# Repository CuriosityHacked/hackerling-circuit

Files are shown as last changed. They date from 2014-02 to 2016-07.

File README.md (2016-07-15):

hackerling-circuit
==================

The eagle design files and supporting documents for the Hackerling Circuit

Be sure to look at the wiki https://github.com/CuriosityHacked/hackerling-circuit/wiki to see the intstructions and more info.

Curiosity Hacked sells full hackerling circuit kits! info@curiosityhacked.org for info. $45 for all the parts and the board prepopulated with SMD accelerometer components.

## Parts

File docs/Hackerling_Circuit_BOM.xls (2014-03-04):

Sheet: v1.3
Part number | qnty
k1 | 1 | 40 pin straight header | S1012EC-40-ND | CONN HEADER .100" SNGL STR 40POS | digikey
k2 | 2 | 330 Ohm resistor array | CSC330N-ND | RES ARRAY 330 OHM 7 RES 8-SIP | digikey
k3 | 1 | Green 5MM LED | 100QBK-ND | RES 100 OHM 1/4W 5% CARBON FILM | digikey
k4 | 1 | Speaker | 254-EMB15-RO | MINI TONE TRANSDUCER | Mouser
k5 | 1 | 100 Ohm Resistor | 100QBK-ND | RES 100 OHM 1/4W 5% CARBON FILM | digikey
k6 | 1 | B-12 Switch | 633-B12JH |  | Mouser
k7 | 1 | 8 pin io expander | MCP23008-E/P-ND | IC I/O EXPANDER I2C 8B 18DIP | digikey
k8 | 1 | 16 pin io expander | MCP23017-E/SP-ND | IC I/O EXPANDER I2C 16B 28SDIP | digikey
k9 | 1 | Bargraph LED Array | 604-DC10GWA |  | Mouser
k10 | 2 | 100 Ohm resistor array | 4608X-2-101LF-ND | RES ARRAY 100 OHM 4 RES 8SIP | digikey
k11 | 1 | Dip Switch | CT2094MS-ND | SWITCH RAISED ACTUATOR 4 SEC | digikey
k12 | 4 | 4x Buttons | SW413-ND | SWITCH TACTILE SPST-NO 0.05A 24V | digikey
k13 | 1 | Red cap | SW260-ND | KEYCAP 12MM SQ RED FITS 12MM | digikey
k14 | 1 | Orange cap | SW956-ND | KEYCAP 12MM SQ ORANGE FITS | digikey
k15 | 1 | Green Cap | SW957-ND | KEYCAP 12MM GRN FITS 12MM | digikey
k16 | 1 | Blue Cap | SW258-ND | KEYCAP 12MM SQ BLUE FITS 12MM | digikey
k17 | 1 | 47 Ohm resistor | 47QBK-ND | RES 47 OHM 1/4W 5% CARBON FILM | digikey
k18 | 1 | 10 uF cap | 445-2863-ND | CAP CER 10UF 6.3V 10% RADIAL | digikey
k19 | 1 | IR photo detector | 425-2501-ND | RECEIVER IR REM CTRL 5V 38KHZ | digikey
k20 | 2 | IR LED | 475-1200-ND | EMITTER IR 850NM 5MM RADIAL | digikey
k21 | 1 | 6 pin right angle header | S1112EC-40-ND | CONN HEADER .100" SNGL R/A 40POS | digikey
k22 | 1 | 502kOhm resistor | 412KXBK-ND | RES 412K OHM 1/4W 1% METAL FILM | digikey
k23 | 1 | 100 Kohm thermistor | BC2424-ND | THERMISTOR NTC 330K 5% RADIAL | digikey
k24 | 1 | 10k pot | PTV09A-4225F-B103-ND | POT 10K OHM 9MM SQ .05W CARB | digikey
k25 | 1 | Pot cap | 450-2034-GRX | KNOB FOR 1/4" SHAFT | Mouser
k26 | 1 | 100 Ohm Pot | 3306K-103-ND | TRIMMER 10K OHM 0.2W PC PIN | digikey
k27 | 1 | 16x2 char LCD | 668-NC-S16205DFYSAY |  | Mouser
a1 | 1 | Accelerometer | 841-MMA8452QR1 | IC ACCELEROMETER 3AXIS 16QFN | Mouser
a2 | 2 | 470 ohm resistor | RMCF0603JT470RCT-ND | RES 470 OHM 1/10W 5% 0603 | digikey
a3 | 1 | 200K resistor | 311-200KGRCT-ND | RES 200K OHM 1/10W 5% 0603 SMD | digikey
a4 | 1 | I2c Level shifter | 296-17988-1-ND | IC VOLT LEVEL TRANSLATOR 8-VSSOP | digikey
a5 | 1 | 4.7 uF Cap | 399-3482-1-ND | CAP CER 4.7UF 6.3V 10% X5R 0603 | digikey
a6 | 2 | 4k7 resistor | CR0603-JW-472ELFCT-ND | RES 4.7K OHM 1/10W 5% 0603 SMD | digikey
a7 | 1 | .1 uF Cap | 311-1341-1-ND | CAP CER 0.1UF 25V 10% X7R 0603 | digikey
a8 | 1 | 1 uF cap | 311-1372-1-ND | CAP CER 1UF 16V Y5V 0603 | digikey
a9 | 1 | 3.3V power supply | TC1016-3.3VCTCT-ND | IC REG LDO 3.3V 80MA SOT23-5 | digikey

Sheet: v1.2
Index | Quantity | Part Number | Description |  | Customer Reference | Quantity needed | Unit Price USD
1 | 30 | CT2094MS-ND | SWITCH RAISED ACTUATOR 4 SEC |  | SW1 | 1 | 0.683 | 0.683
2 | 30 | 445-2863-ND | CAP CER 10UF 6.3V 10% RADIAL | FOR IR RECIEVER | C4 | 1 | 0.328 | 0.328
3 | 25 | 425-2501-ND | RECEIVER IR REM CTRL 5V 38KHZ | FOR IR RECIEVER | IR1 | 1 | 0.768 | 0.768
4 | 30 | 3306K-103-ND | TRIMMER 10K OHM 0.2W PC PIN |  | U8 | 1 | 0.3456 | 0.3456
5 | 30 | 311-1355-1-ND | CAP CER 10UF 10V Y5V 0805 | Optional (to be removed) | C5 | 1 | 0.0824 | 0.0824
6 | 100 | 47QBK-ND | RES 47 OHM 1/4W 5% CARBON FILM | FOR IR RECIEVER | R6 | 1 | 0.0242 | 0.0242
7 | 100 | 311-47ARCT-ND | RES 47 OHM 1/8W 5% 0805 SMD | Optional (to be removed) | R7 | 1 | 0.0077 | 0.0077
8 | 120 | SW413-ND | SWITCH TACTILE SPST-NO 0.05A 24V |  | B1,B2,B3,B4 | 4 | 0.4253 | 1.7012
9 | 100 | 311-1372-1-ND | CAP CER 1UF 16V Y5V 0603 |  | C1 | 1 | 0.0186 | 0.0186
10 | 50 | 399-3482-1-ND | CAP CER 4.7UF 6.3V 10% X5R 0603 |  | C3 | 1 | 0.0518 | 0.0518
11 | 25 | MCP23008-E/P-ND | IC I/O EXPANDER I2C 8B 18DIP |  | IC2 | 1 | 0.85 | 0.85
12 | 100 | 475-1200-ND | EMITTER IR 850NM 5MM RADIAL |  | LED1,LED2,LED3 | 3 | 0.3879 | 1.1637
13 | 60 | CSC330N-ND | RES ARRAY 330 OHM 7 RES 8-SIP |  | RN3,RN4 | 2 | 0.231 | 0.462
14 | 30 | MMA8452QT-ND | IC ACCELEROMETER 3AXIS 16QFN |  | U1 | 1.5 | 1.168 | 1.752
15 | 100 | 296-17988-1-ND | IC VOLT LEVEL TRANSLATOR 8-VSSOP |  | U5 | 1 | 0.3159 | 0.3159
16 | 20 | S1012EC-40-ND | CONN HEADER .100" SNGL STR 40POS |  | STRAIGHT HEADERS | 2 | 0.459 | 0.918
17 | 5 | S1112EC-40-ND | CONN HEADER .100" SNGL R/A 40POS |  | RIGHT ANGLE HEADER | 0.1 | 0.64 | 0.064
18 | 30 | BC2424-ND | THERMISTOR NTC 330K 5% RADIAL |  | R1 | 1 | 0.264 | 0.264
19 | 100 | 412KXBK-ND | RES 412K OHM 1/4W 1% METAL FILM |  | R2 | 1 | 0.0315 | 0.0315
20 | 1 | EG2448-ND | SWITCH TOGGLE SPDT .4VA RT ANG |  | SW2 ALT | 1 | 3.22 | 3.22
21 | 30 | TC1016-3.3VCTCT-ND | IC REG LDO 3.3V 80MA SOT23-5 |  | IC3 | 1 | 0.3 | 0.3
 |  |  |  |  |  |  |  | 0
20 |  | LCD-226 | LCD screen |  |  | 1 | 6.00 | 6 | allelectronics
20 |  | BG-10G | bargraph |  |  | 1 | 1.25 | 1.25 | allelectronics
20 |  | KNB-124 | knob for pot |  |  | 1 | 0.65 | 0.65 | allelectronics
20 |  | PE-52 | buzzer |  |  | 1 | 0.50 | 0.5 | allelectronics
 |  |  | Board |  |  | 1 | 10 | 10
 |  | 652-PTV09A-4225FB102 |  |  |  | 1 | 0.62 | 0.62
 |  | 633-B12JH |  |  |  | 1 | 3.46 | 3.46
 |  | 579-MCP23017-E/SP |  |  |  | 1 | 1 | 1
 |  |  | arduino uno |  |  |  |  | 26.95
 |  |  |  |  |  |  |  | 63.7816

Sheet: v1.1
board part ID | My part ID | description | value | size | qnty used | price |  | Use notes | Retail ID | Retailor | Manufacturer's id
 | MTS-86RT | DPDT ON-ON MINI-TOGGLE SWITCH |  |  |  | 1.25 |  | maybe too big? | MTS-86RT | AllElectronics
R1 | TNR-103 | 10K OHM NTC THERMISTOR |  |  | 1 | 0.65 |  |  | TNR-103 | AllElectronics
 | PE-52 | MINI TONE TRANSDUCER |  |  |  | 0.5 |  |  | PE-52 | AllElectronics
SG1 | PE-38 | MINI TONE TRANSDUCER |  | 0.82" DIA. X 0.15" | 1 | 0.334 |  |  | PE-38 | AllElectronics
 | PB-214 | JUMBO PUSHBUTTON, GREEN |  |  | 0 | 3.75 |  |  | PB-214 | AllElectronics
U2 | LCD-226 | 16 X 2 LCD W/ LED BACKLIGHT |  |  |  | 6 |  |  | LCD-226 | AllElectronics
 | LCD-2161 | 16 X 1 LCD W/ LED BACKLIGHT |  |  |  | 3 |  |  | LCD-2161 | AllElectronics
 | LCD-8002 | 8 CHARACTER X 2 LINE LCD |  |  |  | 3.25 |  |  | LCD-8002 | AllElectronics
 | BG-10G | 10 SEGMENT BARGRAPH, GREEN |  |  |  | 1.5 |  |  | BG-10G | AllElectronics
 | KNB-124 | KNOB FOR 1/4" SHAFT |  |  |  | 0.75 |  |  | KNB-124 | AllElectronics
 | LPC-10K | 10K LIN. POT W/CTR DETENT, PC MT |  |  |  | 0.25 |  |  | LPC-10K | AllElectronics
 | DWS-4S | 4-POLE DIP SWITCH, LOW PROFILE |  |  |  | 1 | digikey | CT2094MS-ND | DWS-4S | AllElectronics
 | CSC330N-ND | RES ARRAY 330 OHM 7 RES 8-SIP |  |  | 2 | 0.49 |  |  | CSC330N-ND | Digikey |  | RN1, RN2 | $1.96
 | 296-17988-1-ND | IC VOLT LEVEL TRANSLATOR 8-VSSOP |  |  | 1 | 0.96 |  |  | 296-17988-1-ND | Digikey |  | I2C TRANSLATOR | $3.84
 | MMA8452QT-ND | IC ACCELEROMETER 3AXIS 16QFN |  |  | 1 | 1.31 |  |  | MMA8452QT-ND | Digikey |  | ACCELEROMETER | $5.24
 | TC1016-3.0VCTCT-ND | IC REG LDO 3V 80MA SOT23-5 |  |  | 0 | 0.43 |  |  | TC1016-3.0VCTCT-ND | Digikey |  | 3.3V REG | $1.72
 | 1219-1083-1-ND | IC REG LDO 3V SOT23-5 |  |  | 1 | 0.4 |  |  | 1219-1083-1-ND | Digikey |  | 3V REG | $1.60
 | MCP23008-E/P-ND | IC I/O EXPANDER I2C 8B 18DIP |  |  | 1 | 1.22 |  |  | MCP23008-E/P-ND | Digikey |  |  | $4.88
 | 1050-1024-ND | ARDUINO UNO BOARD REV3 |  |  | 1 | 26.39 |  |  | 1050-1024-ND | Digikey |  |  | $52.78
 | MCP23017-E/SP-ND | IC I/O EXPANDER I2C 16B 28SDIP |  |  | 1 | 1.44 |  |  | MCP23017-E/SP-ND | Digikey |  |  | $5.76
 | SW414-ND | SWITCH TACTILE SPST-NO 0.05A 24V |  |  | 4 | 0.5124 |  |  | SW414-ND | Digikey |  |  | $12.81
 | SW957-ND | KEYCAP 12MM GRN FITS 12MM |  |  | 1 | 0.279 |  |  | SW957-ND | Digikey |  |  | $2.79
 | SW956-ND | KEYCAP 12MM SQ ORANGE FITS |  |  | 1 | 0.279 |  |  | SW956-ND | Digikey |  |  | $2.79
 | SW260-ND | KEYCAP 12MM SQ RED FITS 12MM |  |  | 1 | 0.279 |  |  | SW260-ND | Digikey |  |  | $2.79
 | SW258-ND | KEYCAP 12MM SQ BLUE FITS 12MM |  |  | 1 | 0.279 |  |  | SW258-ND | Digikey |  |  | $2.79
 | 475-1200-ND | EMITTER IR 850NM 5MM RADIAL |  |  |  | 0.428 |  |  | 475-1200-ND | Digikey |  |  | $4.28
 | EG4912-ND | SWITCH TOGGLE SPDT .4VA R/A |  |  | 1 | 2.99 |  |  | EG4912-ND | Digikey |  |  | $5.98
 | B13EH-ND | SW TOGGLE SPDT .4VA RA BRKT ESD |  |  | 0 | 4.2 |  |  | B13EH-ND | Digikey |  |  | $8.40
 | 425-2501-ND | RECEIVER IR REM CTRL 5V 38KHZ |  |  | 1 | 0.96 |  |  | 425-2501-ND | Digikey |  |  | $3.84
 | 311-1372-1-ND | CAP CER 1UF 16V Y5V 0603 |  |  |  | 0.041 |  |  | 311-1372-1-ND | Digikey |  |  | $0.41
 | 399-3482-1-ND | CAP CER 4.7UF 6.3V 10% X5R 0603 |  |  |  | 0.09 |  |  | 399-3482-1-ND | Digikey |  |  | $0.90
 | 311-200KGRCT-ND | RES 200K OHM 1/10W 5% 0603 SMD |  |  | 1 | 0.0048 |  |  | 311-200KGRCT-ND | Digikey |  |  | $0.48
R3,R4 | CR0603-JW-472ELFCT-ND | RES 4.7K OHM 1/10W 5% 0603 SMD |  |  |  | 0.0044 |  |  | CR0603-JW-472ELFCT-ND | Digikey |  |  | $0.44
 | 311-1341-1-ND | CAP CER 0.1UF 25V 10% X7R 0603 |  |  |  | 0.01 |  |  | 311-1341-1-ND | Digikey |  |  | $1.00
 |  |  |  |  |  | 65.2306

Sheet: Sheet2
therm | 1 | 2 | 3 | 4 | 5 | 6 | 7 | 8 | 9 | 10 | 11 | 12 | 13 | 14 | 15 | 16 | 17 | 18 | 19 | 20 | 21 | 22
1 | 0.500 | 0.667 | 0.750 | 0.800 | 0.833 | 0.857 | 0.875 | 0.889 | 0.900 | 0.909 | 0.917 | 0.923 | 0.929 | 0.933 | 0.938 | 0.941 | 0.944 | 0.947 | 0.950 | 0.952 | 0.955 | 0.957
2 | 0.333 | 0.500 | 0.600 | 0.667 | 0.714 | 0.750 | 0.778 | 0.800 | 0.818 | 0.833 | 0.846 | 0.857 | 0.867 | 0.875 | 0.882 | 0.889 | 0.895 | 0.900 | 0.905 | 0.909 | 0.913 | 0.917
3 | 0.250 | 0.400 | 0.500 | 0.571 | 0.625 | 0.667 | 0.700 | 0.727 | 0.750 | 0.769 | 0.786 | 0.800 | 0.812 | 0.824 | 0.833 | 0.842 | 0.850 | 0.857 | 0.864 | 0.870 | 0.875 | 0.880
4 | 0.200 | 0.333 | 0.429 | 0.500 | 0.556 | 0.600 | 0.636 | 0.667 | 0.692 | 0.714 | 0.733 | 0.750 | 0.765 | 0.778 | 0.789 | 0.800 | 0.810 | 0.818 | 0.826 | 0.833 | 0.840 | 0.846
5 | 0.167 | 0.286 | 0.375 | 0.444 | 0.500 | 0.545 | 0.583 | 0.615 | 0.643 | 0.667 | 0.688 | 0.706 | 0.722 | 0.737 | 0.750 | 0.762 | 0.773 | 0.783 | 0.792 | 0.800 | 0.808 | 0.815
6 | 0.143 | 0.250 | 0.333 | 0.400 | 0.455 | 0.500 | 0.538 | 0.571 | 0.600 | 0.625 | 0.647 | 0.667 | 0.684 | 0.700 | 0.714 | 0.727 | 0.739 | 0.750 | 0.760 | 0.769 | 0.778 | 0.786
7 | 0.125 | 0.222 | 0.300 | 0.364 | 0.417 | 0.462 | 0.500 | 0.533 | 0.562 | 0.588 | 0.611 | 0.632 | 0.650 | 0.667 | 0.682 | 0.696 | 0.708 | 0.720 | 0.731 | 0.741 | 0.750 | 0.759
8 | 0.111 | 0.200 | 0.273 | 0.333 | 0.385 | 0.429 | 0.467 | 0.500 | 0.529 | 0.556 | 0.579 | 0.600 | 0.619 | 0.636 | 0.652 | 0.667 | 0.680 | 0.692 | 0.704 | 0.714 | 0.724 | 0.733
9 | 0.100 | 0.182 | 0.250 | 0.308 | 0.357 | 0.400 | 0.438 | 0.471 | 0.500 | 0.526 | 0.550 | 0.571 | 0.591 | 0.609 | 0.625 | 0.640 | 0.654 | 0.667 | 0.679 | 0.690 | 0.700 | 0.710
10 | 0.091 | 0.167 | 0.231 | 0.286 | 0.333 | 0.375 | 0.412 | 0.444 | 0.474 | 0.500 | 0.524 | 0.545 | 0.565 | 0.583 | 0.600 | 0.615 | 0.630 | 0.643 | 0.655 | 0.667 | 0.677 | 0.688
 | 0.2424242424 | 0.3333333333 | 0.3692307692 | 0.380952381 | 0.380952381 | 0.375 | 0.3660130719 | 0.3555555556 | 0.3444976077 | 0.3333333333 | 0.3223443223 | 0.3116883117 | 0.3014492754 | 0.2916666667 | 0.2823529412 | 0.2735042735 | 0.2651072125 | 0.2571428571 | 0.249589491 | 0.2424242424 | 0.2356241234 | 0.2291666667
 | 0.05194805195 | 0.08333333333 | 0.1025641026 | 0.1142857143 | 0.1212121212 | 0.125 | 0.1266968326 | 0.126984127 | 0.1263157895 | 0.125 | 0.1232492997 | 0.1212121212 | 0.118993135 | 0.1166666667 | 0.1142857143 | 0.1118881119 | 0.1095008052 | 0.1071428571 | 0.1048275862 | 0.1025641026 | 0.1003584229 | 0.09821428571

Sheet: Sheet3
board part ID | My part ID | description | value | size | qnty used | qnty have | price | Use notes | Retail ID | Retailor | Manufacturer's id
 | MTS-86RT | DPDT ON-ON MINI-TOGGLE SWITCH |  |  |  | 2 | 1.25 | maybe too big? | MTS-86RT | AllElectronics
R1 | TNR-103 | 10K OHM NTC THERMISTOR |  |  | 1 | 3 | 0.65 |  | TNR-103 | AllElectronics
SG1 | PE-38 | MINI TONE TRANSDUCER |  | 0.82" DIA. X 0.15" | 1 | 3 | 0.334 |  | PE-38 | AllElectronics
 | PB-214 | JUMBO PUSHBUTTON, GREEN |  |  | 0 | 1 | 3.75 |  | PB-214 | AllElectronics
 | LCD-2161 | 16 X 1 LCD W/ LED BACKLIGHT |  |  |  | 2 | 3 |  | LCD-2161 | AllElectronics
 | LCD-8002 | 8 CHARACTER X 2 LINE LCD |  |  |  | 2 | 3.25 |  | LCD-8002 | AllElectronics
 |  |  |  |  |  |  |  |  |  |  |  | I2C TRANSLATOR | $3.84
 | TC1016-3.0VCTCT-ND | IC REG LDO 3V 80MA SOT23-5 |  |  | 0 | 4 | 0.43 |  | TC1016-3.0VCTCT-ND | Digikey |  | 3.3V REG | $1.72
 | 1219-1083-1-ND | IC REG LDO 3V SOT23-5 |  |  | 1 | 4 | 0.4 |  | 1219-1083-1-ND | Digikey |  | 3V REG | $1.60
 | EG4912-ND | SWITCH TOGGLE SPDT .4VA R/A |  |  | 1 | 2 | 2.99 |  | EG4912-ND | Digikey |  |  | $5.98
 | B13EH-ND | SW TOGGLE SPDT .4VA RA BRKT ESD |  |  | 0 | 2 | 4.2 |  | B13EH-ND | Digikey |  |  | $8.40
 | SW957-ND | KEYCAP 12MM GRN FITS 12MM |  |  | 1 | 10 | 0.279 |  | SW957-ND | Digikey |  |  | $2.79
 | SW956-ND | KEYCAP 12MM SQ ORANGE FITS |  |  | 1 | 10 | 0.279 |  | SW956-ND | Digikey |  |  | $2.79
 | SW260-ND | KEYCAP 12MM SQ RED FITS 12MM |  |  | 1 | 10 | 0.279 |  | SW260-ND | Digikey |  |  | $2.79
 | SW258-ND | KEYCAP 12MM SQ BLUE FITS 12MM |  |  | 1 | 10 | 0.279 |  | SW258-ND | Digikey |  |  | $2.79

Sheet: Sheet4
 |  |  |  |  | qnty | ordered
B1 |  | SWITCH_BCF-4000 | SWITCH_B3F-4000 | hackerscouts | 120 | 2013-01-02 | SW414-ND | SWITCH TACTILE SPST-NO 0.05A 24V |  |  |  | 0.5124 |  |  | SW414-ND | Digikey
B2 |  | SWITCH_BCF-4000 | SWITCH_B3F-4000 | hackerscouts | 120 | 2013-01-02 | SW414-ND | SWITCH TACTILE SPST-NO 0.05A 24V |  |  |  | 0.5124 |  |  | SW414-ND | Digikey
B3 |  | SWITCH_BCF-4000 | SWITCH_B3F-4000 | hackerscouts | 120 | 2013-01-02 | SW414-ND | SWITCH TACTILE SPST-NO 0.05A 24V |  |  |  | 0.5124 |  |  | SW414-ND | Digikey
B4 |  | SWITCH_BCF-4000 | SWITCH_B3F-4000 | hackerscouts | 120 | 2013-01-02 | SW414-ND | SWITCH TACTILE SPST-NO 0.05A 24V |  |  |  | 0.5124 |  |  | SW414-ND | Digikey
C1 | 1uF | C-USC0603K | C0603K | resistor | 100 | 2013-01-02 | 311-1372-1-ND | CAP CER 1UF 16V Y5V 0603 |  |  | 10 | 0.041 |  |  | 311-1372-1-ND | Digikey
C2 | 0.1uF | C-USC0603K | C0603K | resistor | 100 | 2012-11-30 | 311-1341-1-ND | CAP CER 0.1UF 25V 10% X7R 0603 |  |  | 100 | 0.01 |  |  | 311-1341-1-ND | Digikey
C3 | 4.7uF | C-USC0603K | C0603K | resistor | 50 | 2013-01-02 | 399-3482-1-ND | CAP CER 4.7UF 6.3V 10% X5R 0603 |  |  | 10 | 0.09 |  |  | 399-3482-1-ND | Digikey
C4 | 10uF | C-US050-050X075 | C050-050X075 | rcl | 30 | 2013-01-02 | 445-2863-ND (http://www.digikey.com/scripts/DKSearch/dksus.dll?Detail&itemSeq=123546165&uq=634926983742302205) | CAP CER 10UF 6.3V 10% RADIAL
C5 | 10uF | C-USC0805K | C0805K | resistor | 30 | 2013-01-02 | 311-1355-1-ND (http://www.digikey.com/scripts/DKSearch/dksus.dll?Detail&itemSeq=124219124&uq=634926995471126111) | CAP CER 10UF 10V Y5V 0805
DZ1 | LB10 | LB10 | LB10 | led | 20 | 2012-12-06 | BG-10G | 10 SEGMENT BARGRAPH, GREEN |  |  | 4 | 1.5 |  |  | BG-10G
IC1 | MCP23017SP | MCP23017SP | DIL28-3 | adafruit | 30 | 2013-01-02 | MCP23017-E/SP-ND | IC I/O EXPANDER I2C 16B 28SDIP | mouser | 1 | 4 | 1.44 |  |  | MCP23017-E/SP-ND | Digikey
IC2 | MCP2300X/P | MCP2300X/P | DIL18 | adafruit | 25 | 2013-01-02 | MCP23008-E/P-ND | IC I/O EXPANDER I2C 8B 18DIP |  | 1 | 4 | 1.22 |  |  | MCP23008-E/P-ND | Digikey
IC3 | MIC5219BM5 | MIC5219BM5 | SOT23-5 | v-reg-micrel | 30 | 2013-01-02 | TC1016-3.3VCTCT-ND (http://www.digikey.com/scripts/DKSearch/dksus.dll?Detail&itemSeq=124254332&uq=634927446236049921) | IC REG LDO 3.3V 80MA SOT23-5
IR1 | PNA460XM | PNA460XM | PNA460XM | adafruit | 25 | 2013-01-02 | 425-2501-ND | RECEIVER IR REM CTRL 5V 38KHZ |  | 1 | 4 | 0.96 |  |  | 425-2501-ND | Digikey
JP1 |  | M02LOCK | 1X02_LOCK | SparkFun |  | 2013-01-02 | S1012EC-40-ND (http://www.digikey.com/scripts/DKSearch/dksus.dll?Detail&itemSeq=124244704&uq=634927353556944550) | straight header 2x
JP2 |  | M02LOCK | 1X02_LOCK | SparkFun |  | 2013-01-02 | S1012EC-40-ND (http://www.digikey.com/scripts/DKSearch/dksus.dll?Detail&itemSeq=124244704&uq=634927353556944550) | straight header 2x
LED1 |  | LED5MM | LED5MM | SparkFun | 100 | 2013-01-02 | 475-1200-ND | EMITTER IR 850NM 5MM RADIAL |  |  | 10 | 0.428 |  |  | 475-1200-ND | Digikey
LED2 |  | LED5MM | LED5MM | SparkFun | 100 | 2013-01-02 | 475-1200-ND | EMITTER IR 850NM 5MM RADIAL |  |  | 10 | 0.428 |  |  | 475-1200-ND | Digikey
LED3 |  | LED5MM | LED5MM | SparkFun | 100 | 2013-01-02 | 475-1200-ND | EMITTER IR 850NM 5MM RADIAL |  |  | 10 | 0.428 |  |  | 475-1200-ND | Digikey
R1 | THERMISTOR-5 | THERMISTOR-5 | R-5 | varistor | 30 | 2013-01-02 | BC2424-ND (http://www.digikey.com/scripts/DKSearch/dksus.dll?Detail&itemSeq=124251169&uq=634927409292604193) | THERMISTOR NTC 330K 5% RADIAL
R2 |  | R-EU_0204/7 | 0204/7 | resistor | 100 | 2013-01-02 | 412KXBK-ND (http://www.digikey.com/scripts/DKSearch/dksus.dll?Detail&itemSeq=124251684&uq=634927409292604193) | RES 412K OHM 1/4W 1% METAL FILM
R3 | 4k7 | RESISTOR0603-RES | 0603-RES | SparkFun | 100 | 2012-11-30 | CR0603-JW-472ELFCT-ND | RES 4.7K OHM 1/10W 5% 0603 SMD |  |  | 100 | 0.0044 |  |  | CR0603-JW-472ELFCT-ND | Digikey
R4 | 4k7 | RESISTOR0603-RES | 0603-RES | SparkFun | 100 | 2012-11-30 | CR0603-JW-472ELFCT-ND | RES 4.7K OHM 1/10W 5% 0603 SMD |  |  | 100 | 0.0044 |  |  | CR0603-JW-472ELFCT-ND | Digikey
R5 | 200K | RESISTOR0603-RES | 0603-RES | SparkFun | 100 | 2012-11-30 | 311-200KGRCT-ND | RES 200K OHM 1/10W 5% 0603 SMD |  | 1 | 100 | 0.0048 |  |  | 311-200KGRCT-ND | Digikey
R6 | 47 | R-US_0204/7 | 0204/7 | resistor | 100 | 2013-01-02 | 47QBK-ND (http://www.digikey.com/scripts/DKSearch/dksus.dll?Detail&itemSeq=124219190&uq=634926999547019698) | RES 47 OHM 1/4W 5% CARBON FILM
R7 | 47 | R-US_R0805 | R0805 | rcl | 100 | 2013-01-02 | 311-47ARCT-ND (http://www.digikey.com/scripts/DKSearch/dksus.dll?Detail&itemSeq=124219219&uq=634926999547019698) | RES 47 OHM 1/8W 5% 0805 SMD
RN3 |  | G07R | SIL8 | resistor-sil | 60 | 2013-01-02 | CSC330N-ND | RES ARRAY 330 OHM 7 RES 8-SIP |  | 2 | 4 | 0.49 |  |  | CSC330N-ND | Digikey
RN4 |  | G07R | SIL8 | resistor-sil | 60 | 2013-01-02 | CSC330N-ND | RES ARRAY 330 OHM 7 RES 8-SIP |  | 2 | 4 | 0.49 |  |  | CSC330N-ND | Digikey
SERVO1 |  | M03LOCK | 1X03_LOCK | SparkFun |  | 2013-01-02 | S1112EC-40-ND (http://www.digikey.com/scripts/DKSearch/dksus.dll?Detail&itemSeq=124245388&uq=634927353556944550) | right angle
SERVO2 |  | M03LOCK | 1X03_LOCK | SparkFun |  | 2013-01-02 | S1112EC-40-ND (http://www.digikey.com/scripts/DKSearch/dksus.dll?Detail&itemSeq=124245388&uq=634927353556944550) | right angle
SG1 | BUZZERNS | BUZZERNS | BUZZER-12MM-NS | SparkFun | 20 | 2012-12-06 | PE-52 | MINI TONE TRANSDUCER |  |  | 4 | 0.5 |  |  | PE-52 | AllElectronics
SW1 |  | SW_DIP-4 | EDG-04 | special | 30 | 2013-01-02 | DWS-4S | 4-POLE DIP SWITCH, LOW PROFILE |  |  | 3 | 1 | digikey | CT2094MS-ND | DWS-4S | AllElectronics | CT2094MS-ND (http://www.digikey.com/scripts/DKSearch/dksus.dll?Detail&itemSeq=123452126&uq=634926983742302205) | SWITCH RAISED ACTUATOR 4 SEC
SW2 | SWITCH_B13EH | SWITCH_B13EH | SWITCH_B13EH | hackerscouts | 25 | 2013-01-02 | B12JH | mouser
U4 | ACCELEROMETER | ACCELEROMETER | ACCELEROMETER | hackerscouts |  | 2013-01-02 | S1012EC-40-ND (http://www.digikey.com/scripts/DKSearch/dksus.dll?Detail&itemSeq=124244704&uq=634927353556944550) | straight header 6x
U6 | ACCELEROMETER | ACCELEROMETER | ACCELEROMETER | hackerscouts |  | 2013-01-02 |  | duplicate...
U8 | SML_POT | SML_POT | SML_POT | hackerscouts | 30 | 2013-01-02 | 3306K-103-ND (http://www.digikey.com/scripts/DKSearch/dksus.dll?Detail&itemSeq=124219018&uq=634926999547019698) | TRIMMER 10K OHM 0.2W PC PIN
U1 | MMA8452Q | MMA8452Q | QFN-16(5X3) | hackerscouts | 30 | 2013-01-02 | MMA8452QT-ND | IC ACCELEROMETER 3AXIS 16QFN |  | 1 | 4 | 1.31 |  |  | MMA8452QT-ND | Digikey
U2 | LCD_16X2 | LCD_16X2 | LCD_16X2 | hackerscouts | 20 | 2012-12-06 | LCD-226 | 16 X 2 LCD W/ LED BACKLIGHT |  |  | 1 | 6 |  |  | LCD-226 | AllElectronics
U3 | ARDUINOR3-BPLACE | ARDUINOR3-BPLACE | ARDUINOR3-BPLACE | adafruit |  | 2013-01-02 | S1012EC-40-ND (http://www.digikey.com/scripts/DKSearch/dksus.dll?Detail&itemSeq=124244704&uq=634927353556944550) | straight header 10,8,6,5x → 29x
U5 | PCA9306 | PCA9306 | VSSOP-8 | hackerscouts | 100 | 2013-01-02 | 296-17988-1-ND | IC VOLT LEVEL TRANSLATOR 8-VSSOP |  | 1 | 4 | 0.96 |  |  | 296-17988-1-ND | Digikey
U7 | POT | POT | ALS_POT | hackerscouts | 20 | 2012-12-06 | LPC-10K | 10K LIN. POT W/CTR DETENT, PC MT |  |  | 4 | 0.25 |  |  | LPC-10K | AllElectronics
 |  |  |  |  |  |  | 652-PTV09A-4225FB102 (http://www.mouser.com/Search/ProductDetail.aspx)
 |  |  |  |  | 20 | 2012-12-06 | KNB-124 | KNOB FOR 1/4" SHAFT |  |  | 1 | 0.75 |  |  | KNB-124 | AllElectronics
 |  |  |  |  | 20 | 2012-12-15 | 1050-1024-ND | ARDUINO UNO BOARD REV3 |  | 1 | 2 | 26.39 |  |  | 1050-1024-ND | Digikey

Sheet: Sheet5
 |  | Header prices
 |  |  | Price per part |  |  | price per pin
 | part | #pins | @10 | @25 | @100 | @10 | @25 | @100
 | S1012EC-40-ND | 40 | 0.459 | 0.459 | 0.378 | 0.011475 | 0.011475 | 0.009450
 | 952-2267-ND | 5 | 0.275 | 0.1952 | 0.1375 | 0.055000 | 0.039040 | 0.027500
 | 952-1843-ND | 10 | 0.383 | 0.286 | 0.22 | 0.038300 | 0.028600 | 0.022000
 | 952-1901-ND | 20 | 0.63 | 0.54 | 0.423 | 0.031500 | 0.027000 | 0.021150
 | A26509-40-ND | 40 | 1.703 | 1.703 | 1.402 | 0.042575 | 0.042575 | 0.035050
 | SAM1035-50-ND | 50 | 1.951 | 1.951 | 1.6065 | 0.039020 | 0.039020 | 0.032130
right angle | S1112EC-40-ND | 40 | 0.569 | 0.569 | 0.468 | 0.014225 | 0.014225 | 0.011700 |  |  |  |  |  |  | 13
 | 609-3408-ND | 20 | 0.946 | 0.8904 | 0.8162 | 0.047300 | 0.044520 | 0.040810 |  |  |  |  |  |  | 2.564949357
 |  |  |  |  |  | #DIV/0! | #DIV/0! | #DIV/0! |  |  |  |  |  |  | 13
 |  | 9.343093871
 |  | 2.234637447
 |  | 0.0005618902306
Beta values | 25 | 358.15
3977 | 10000 | 1070.309272 | Rref | A | B | C | D
 |  | 585.5158953 | 10000 | -14.6337 | 4557.725 | -98275 | -7522357
 |  |  |  |  |  |  |  |  |  | 0.01953125
 |  |  | Temps:
 |  |  | 25C | 85C | 100F | 32F |  | using10k | using 10k | dV/dT | bits/degree
Part # | Beta values | R25 | 298.15 | 358.15 | 316.483 | 273.15 |  | V100 | V32 |  |  |  |  | 273.15 | 277.15 | 281.15 | 285.15 | 289.15 | 293.15 | 297.15 | 301.15 | 305.15 | 309.15 | 313.15 | 317.15
BC2301-ND | 3977 | 10000 | 10000.0 | 1070.3 | 4617.7 | 33900.4 |  | 1.579490083 | 3.861058755 | 0.03355248046 | 1.717887 |  |  | 33900.4 | 27475.4 | 22401.7 | 18369.8 | 15146.5 | 12554.7 | 10459.1 | 8755.7 | 7363.9 | 6221.2 | 5278.5 | 4497.3
 | 3400 | 10000 | 10000.0 | 1480.2 | 5165.5 | 28397.5 |  | 1.70304354 | 3.697833181 | 0.02933514178 | 1.501959259 |  |  | 28397.5 | 23728.0 | 19927.8 | 16818.5 | 14261.0 | 12147.1 | 10391.2 | 8926.1 | 7698.2 | 6664.7 | 5791.2 | 5050.1
 | 3892 | 10000 | 10000.0 | 1122.7 | 4694.6 | 33027.3 |  | 1.597388621 | 3.837947073 | 0.03294938901 | 1.687008717 |  |  | 33027.3 | 26888.3 | 22018.8 | 18132.6 | 15012.7 | 12493.8 | 10449.1 | 8780.6 | 7412.3 | 6284.7 | 5351.1 | 4574.7
 | 4750 | 10000 | 10000.0 | 693.2 | 3973.8 | 42979.3 |  | 1.421864297 | 4.056235964 | 0.03874075981 | 1.983526902 |  |  | 42979.3 | 33439.6 | 26203.8 | 20674.6 | 16419.5 | 13122.3 | 10550.8 | 8532.5 | 6938.8 | 5673.0 | 4662.1 | 3850.3
BC2424-ND | 4570 | 330000 | 330000.0 | 25311.4 | 135801.1 | 1342074.2 |  | 1.457715901 | 4.013201663 | 0.03758067298 | 1.924130457 |  |  | 1342074.2 | 1054164.0 | 833726.9 | 663739.8 | 531755.1 | 428601.0 | 347469.0 | 283269.7 | 232172.1 | 191273.7 | 158361.9 | 131739.0
 | 4370 | 10000 | 10000.0 | 858.2 | 4278.2 | 38247.1 |  | 1.49816806 | 3.963669216 | 0.03625736994 | 1.856377341
 |  | 10000 | 10000.0 | 10000.0 | 10000.0 | 10000.0 |  | 2.5 | 2.5 | 0 | 0
 |  | 10000 | 10000.0 | 10000.0 | 10000.0 | 10000.0 |  |  |  |  |  |  | 1000 | 4.86 | 4.82 | 4.79 | 4.74 | 4.69 | 4.63 | 4.56 | 4.49 | 4.40 | 4.31 | 4.20 | 4.09
 |  |  |  |  |  |  |  |  |  |  |  |  | 2000 | 4.72 | 4.66 | 4.59 | 4.51 | 4.42 | 4.31 | 4.20 | 4.07 | 3.93 | 3.78 | 3.63 | 3.46
 |  |  |  |  |  |  |  |  |  |  |  |  | 3000 | 4.59 | 4.51 | 4.41 | 4.30 | 4.17 | 4.04 | 3.89 | 3.72 | 3.55 | 3.37 | 3.19 | 3.00
 |  |  |  |  |  |  |  |  |  |  |  |  | 4000 | 4.47 | 4.36 | 4.24 | 4.11 | 3.96 | 3.79 | 3.62 | 3.43 | 3.24 | 3.04 | 2.84 | 2.65
 |  |  |  |  |  |  |  |  |  |  |  |  | 5000 | 4.36 | 4.23 | 4.09 | 3.93 | 3.76 | 3.58 | 3.38 | 3.18 | 2.98 | 2.77 | 2.57 | 2.37
 |  |  |  |  |  | 135801.148 | 1342074.16 | 300000 | 1.55806322 | 4.086521159 | 0.03718320499 | 1.903901945 | 6000 | 4.25 | 4.10 | 3.94 | 3.77 | 3.58 | 3.38 | 3.18 | 2.97 | 2.76 | 2.55 | 2.34 | 2.14
 |  |  |  |  |  | 135801.148 | 1342074.16 | 310000 | 1.523113485 | 4.061785459 | 0.03733341139 | 1.911593005 | 7000 | 4.14 | 3.98 | 3.81 | 3.62 | 3.42 | 3.21 | 3.00 | 2.78 | 2.56 | 2.35 | 2.15 | 1.96
 |  |  |  |  |  | 135801.148 | 1342074.16 | 320000 | 1.489697301 | 4.037347407 | 0.03746544273 | 1.918353443 | 8000 | 4.05 | 3.87 | 3.68 | 3.48 | 3.27 | 3.05 | 2.83 | 2.61 | 2.40 | 2.19 | 1.99 | 1.80
 |  |  |  |  |  | 135801.148 | 1342074.16 | 330000 | 1.457715901 | 4.013201663 | 0.03758067298 | 1.924253609 | 9000 | 3.95 | 3.77 | 3.57 | 3.36 | 3.14 | 2.91 | 2.69 | 2.47 | 2.25 | 2.04 | 1.85 | 1.67
 |  |  |  |  |  | 135801.148 | 1342074.16 | 340000 | 1.427078818 | 3.989343015 | 0.03768035583 | 1.929357697 | 10000 | 3.86 | 3.67 | 3.46 | 3.24 | 3.01 | 2.78 | 2.56 | 2.33 | 2.12 | 1.92 | 1.73 | 1.55
 |  |  |  |  |  | 135801.148 | 1342074.16 | 350000 | 1.397703037 | 3.96576637 | 0.03776563725 | 1.933724386 | 11000 | 3.78 | 3.57 | 3.35 | 3.13 | 2.90 | 2.67 | 2.44 | 2.22 | 2.01 | 1.81 | 1.62 | 1.45
 |  |  |  |  |  | 135801.148 | 1342074.16 | 360000 | 1.369512238 | 3.942466761 | 0.0378375665 | 1.937407399 | 12000 | 3.69 | 3.48 | 3.26 | 3.02 | 2.79 | 2.56 | 2.33 | 2.11 | 1.90 | 1.71 | 1.53 | 1.36
 |  |  |  |  |  | 135801.148 | 1342074.16 | 370000 | 1.342436139 | 3.919439331 | 0.03789710577 | 1.940456005 | 13000 | 3.61 | 3.39 | 3.16 | 2.93 | 2.69 | 2.46 | 2.23 | 2.01 | 1.81 | 1.62 | 1.44 | 1.29
 |  |  |  |  |  | 135801.148 | 1342074.16 | 380000 | 1.316409905 | 3.896679339 | 0.03794513875 | 1.94291545 | 14000 | 3.54 | 3.31 | 3.08 | 2.84 | 2.60 | 2.36 | 2.14 | 1.92 | 1.72 | 1.54 | 1.37 | 1.22
 |  |  |  |  |  | 135801.148 | 1342074.16 | 390000 | 1.291373635 | 3.874182154 | 0.03798247821 | 1.944827354 | 15000 | 3.47 | 3.23 | 2.99 | 2.75 | 2.51 | 2.28 | 2.05 | 1.84 | 1.65 | 1.47 | 1.30 | 1.15
 |  |  |  |  |  | 135801.148 | 1342074.16 | 400000 | 1.267271902 | 3.851943249 | 0.03800987275 | 1.946230043 | 16000 | 3.40 | 3.16 | 2.92 | 2.67 | 2.43 | 2.20 | 1.98 | 1.77 | 1.58 | 1.40 | 1.24 | 1.10
 |  |  |  |  |  | 135801.148 | 1342074.16 | 410000 | 1.244053338 | 3.829958202 | 0.03802801271 | 1.947158869 | 17000 | 3.33 | 3.09 | 2.84 | 2.60 | 2.36 | 2.12 | 1.90 | 1.70 | 1.51 | 1.34 | 1.18 | 1.05
 |  |  |  |  |  | 135801.148 | 1342074.16 | 420000 | 1.221670273 | 3.808222691 | 0.03803753557 | 1.947646471 | 18000 | 3.27 | 3.02 | 2.77 | 2.53 | 2.28 | 2.05 | 1.84 | 1.64 | 1.45 | 1.28 | 1.13 | 1.00
 |  |  |  |  |  | 135801.148 | 1342074.16 | 430000 | 1.200078406 | 3.786732492 | 0.03803903067 | 1.947723025 | 19000 | 3.20 | 2.96 | 2.71 | 2.46 | 2.22 | 1.99 | 1.78 | 1.58 | 1.40 | 1.23 | 1.09 | 0.96
 |  |  |  |  |  | 135801.148 | 1342074.16 | 440000 | 1.179236517 | 3.765483475 | 0.0380330435 | 1.947416462 | 20000 | 3.14 | 2.89 | 2.64 | 2.39 | 2.15 | 1.93 | 1.72 | 1.52 | 1.35 | 1.19 | 1.04 | 0.92
 |  |  |  |  |  | 135801.148 | 1342074.16 | 450000 | 1.159106196 | 3.744471602 | 0.0380200795 | 1.946752663 | 21000 | 3.09 | 2.83 | 2.58 | 2.33 | 2.10 | 1.87 | 1.66 | 1.47 | 1.30 | 1.14 | 1.00 | 0.88
 |  |  |  |  |  | 135801.148 | 1342074.16 | 460000 | 1.139651614 | 3.723692925 | 0.03800060751 | 1.945755633 | 22000 | 3.03 | 2.78 | 2.52 | 2.28 | 2.04 | 1.82 | 1.61 | 1.42 | 1.25 | 1.10 | 0.97 | 0.85
 |  |  |  |  |  | 135801.148 | 1342074.16 | 470000 | 1.120839309 | 3.703143584 | 0.03797506288 | 1.944447664
 |  |  |  |  |  | 135801.148 | 1342074.16 | 480000 | 1.10263799 | 3.682819804 | 0.0379438502 | 1.942849473
 |  |  |  |  |  | 135801.148 | 1342074.16 | 490000 | 1.085018368 | 3.662717889 | 0.03790734591 | 1.940980333
 |  |  |  |  |  | 135801.148 | 1342074.16 | 500000 | 1.067952995 | 3.642834228 | 0.03786590049 | 1.938858192
 |  |  |  |  |  | 135801.148 | 1342074.16 | 510000 | 1.051416124 | 3.623165284 | 0.03781984059 | 1.936499774

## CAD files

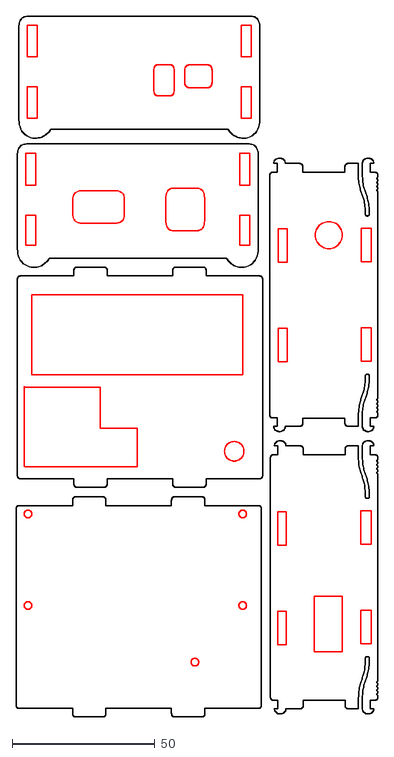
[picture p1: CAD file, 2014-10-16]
enclosure/HackerlingBoxAcrylicFixed.dxf
126.6 x 245.2

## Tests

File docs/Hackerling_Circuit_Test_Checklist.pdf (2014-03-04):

## Hackerling Circuit Test Checklist

Test the Arduino
☐Computer detects Arduino and successfully uploads program

Load the program - MMA8452Q_Example
☐Accelerometer readings display to Serial (9600bps)

Load the program - CH_buttontest
☐Up Button makes a sound

☐Down Button makes a sound

☐Left Button makes a sound

☐Right Button makes a sound

☐Speaker Works

Load the program - CH_ledandswitches ☐Toggle Switch turns on/off Green LED

☐Green LED works

☐DIP Switch 2 turns on/off lights from Bargraph

☐DIP Switch 3 turns on/off lights from Bargraph

☐DIP Switch 4 turns on/off lights from Bargraph

Load program - CH_potandtherm
☐Thermistor readings display to serial (9600bps), frequency of updates based on Potentiometer

☐Potentiometer changes frequency of Bargraph updates

☐All Bargraph lights work

Load program - Servo / Sweep
☐Servo attached to S1 will swing back and forth

Load program - Hackerling_Shield / Overview
☐Tones will sound when IR signal detected

☐Down button will send IR signal (use other HC to detect)

## Hackerling Circuit Test Checklist

Test the Arduino
☐Computer detects Arduino and successfully uploads program

Load the program - MMA8452Q_Example
☐Accelerometer readings display to Serial (9600bps)

Load the program - CH_buttontest
☐Up Button makes a sound

☐Down Button makes a sound

☐Left Button makes a sound

☐Right Button makes a sound

☐Speaker Works

Load the program - CH_ledandswitches ☐Toggle Switch turns on/off Green LED

☐Green LED works

☐DIP Switch 2 turns on/off lights from Bargraph

☐DIP Switch 3 turns on/off lights from Bargraph

☐DIP Switch 4 turns on/off lights from Bargraph

Load program - CH_potandtherm
☐Thermistor readings display to serial (9600bps), frequency of updates based on Potentiometer

☐Potentiometer changes frequency of Bargraph updates

☐All Bargraph lights work

Load program - Servo / Sweep
☐Servo attached to S1 will swing back and forth

Load program - Hackerling_Shield / Overview
☐Tones will sound when IR signal detected

☐Down button will send IR signal (use other HC to detect)

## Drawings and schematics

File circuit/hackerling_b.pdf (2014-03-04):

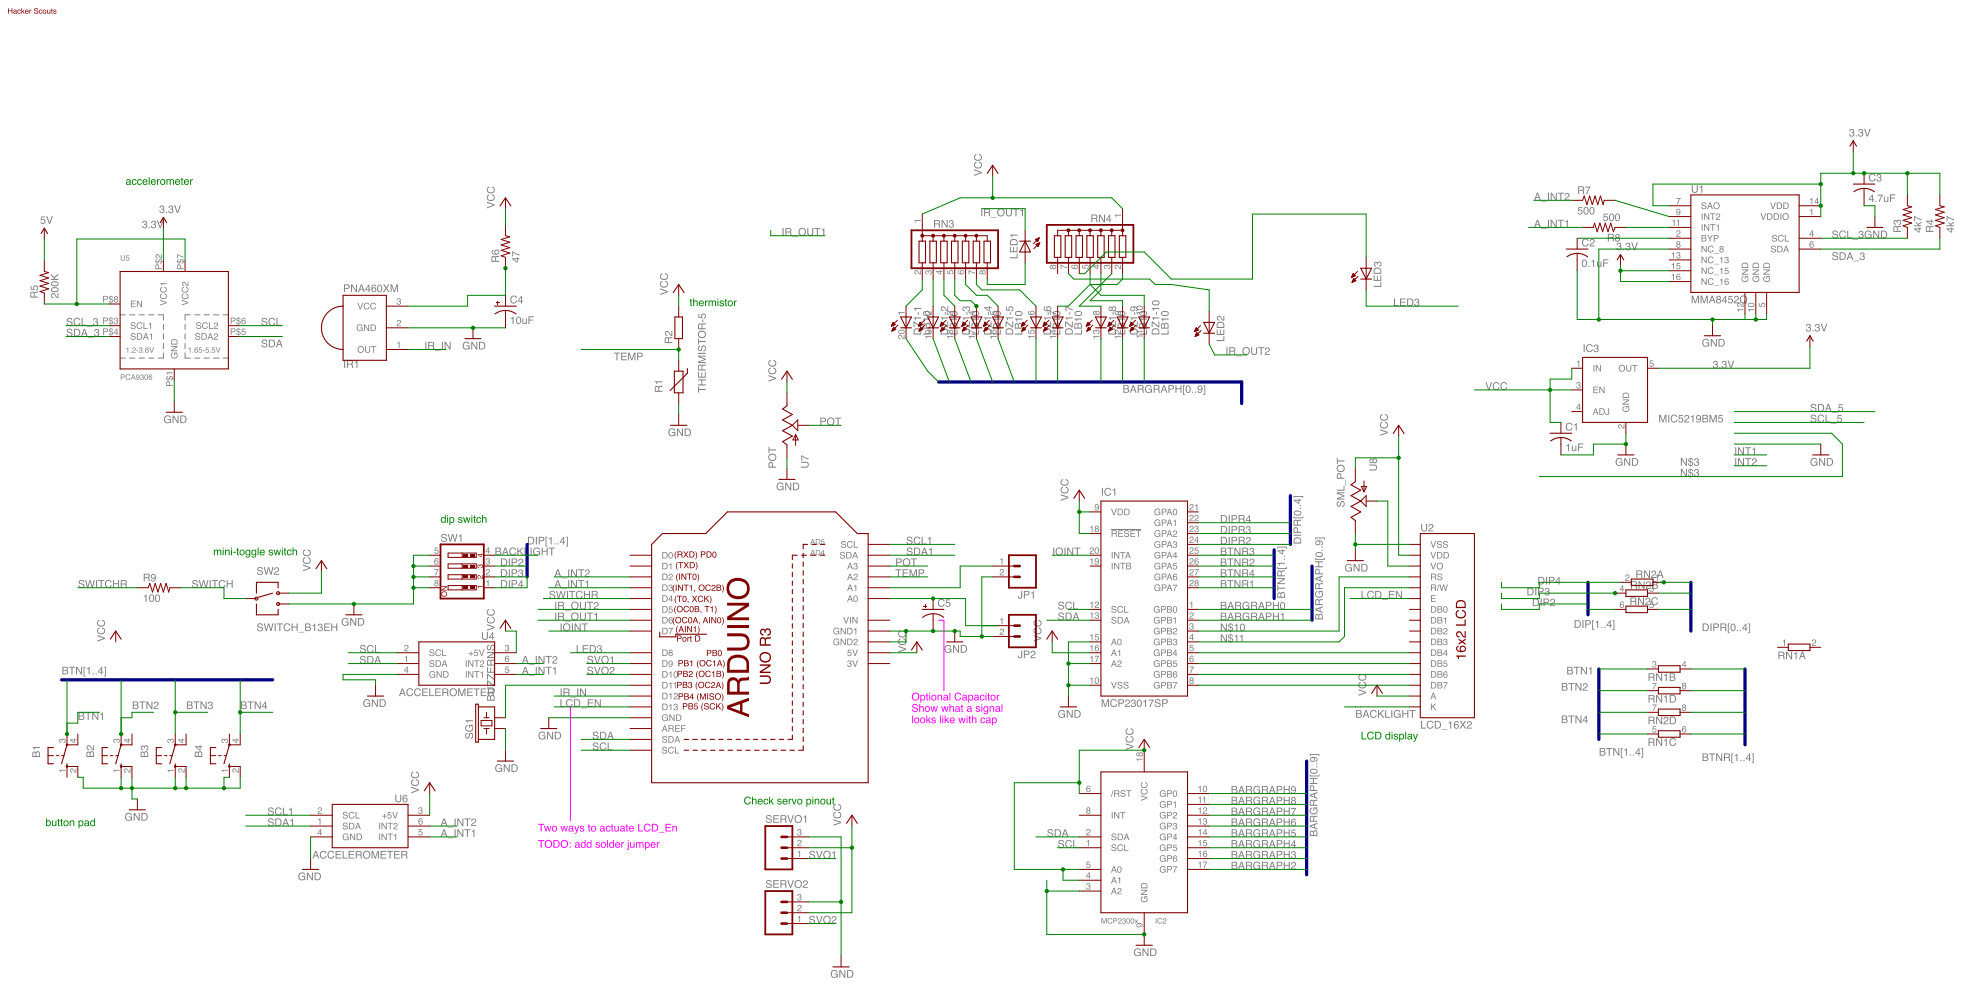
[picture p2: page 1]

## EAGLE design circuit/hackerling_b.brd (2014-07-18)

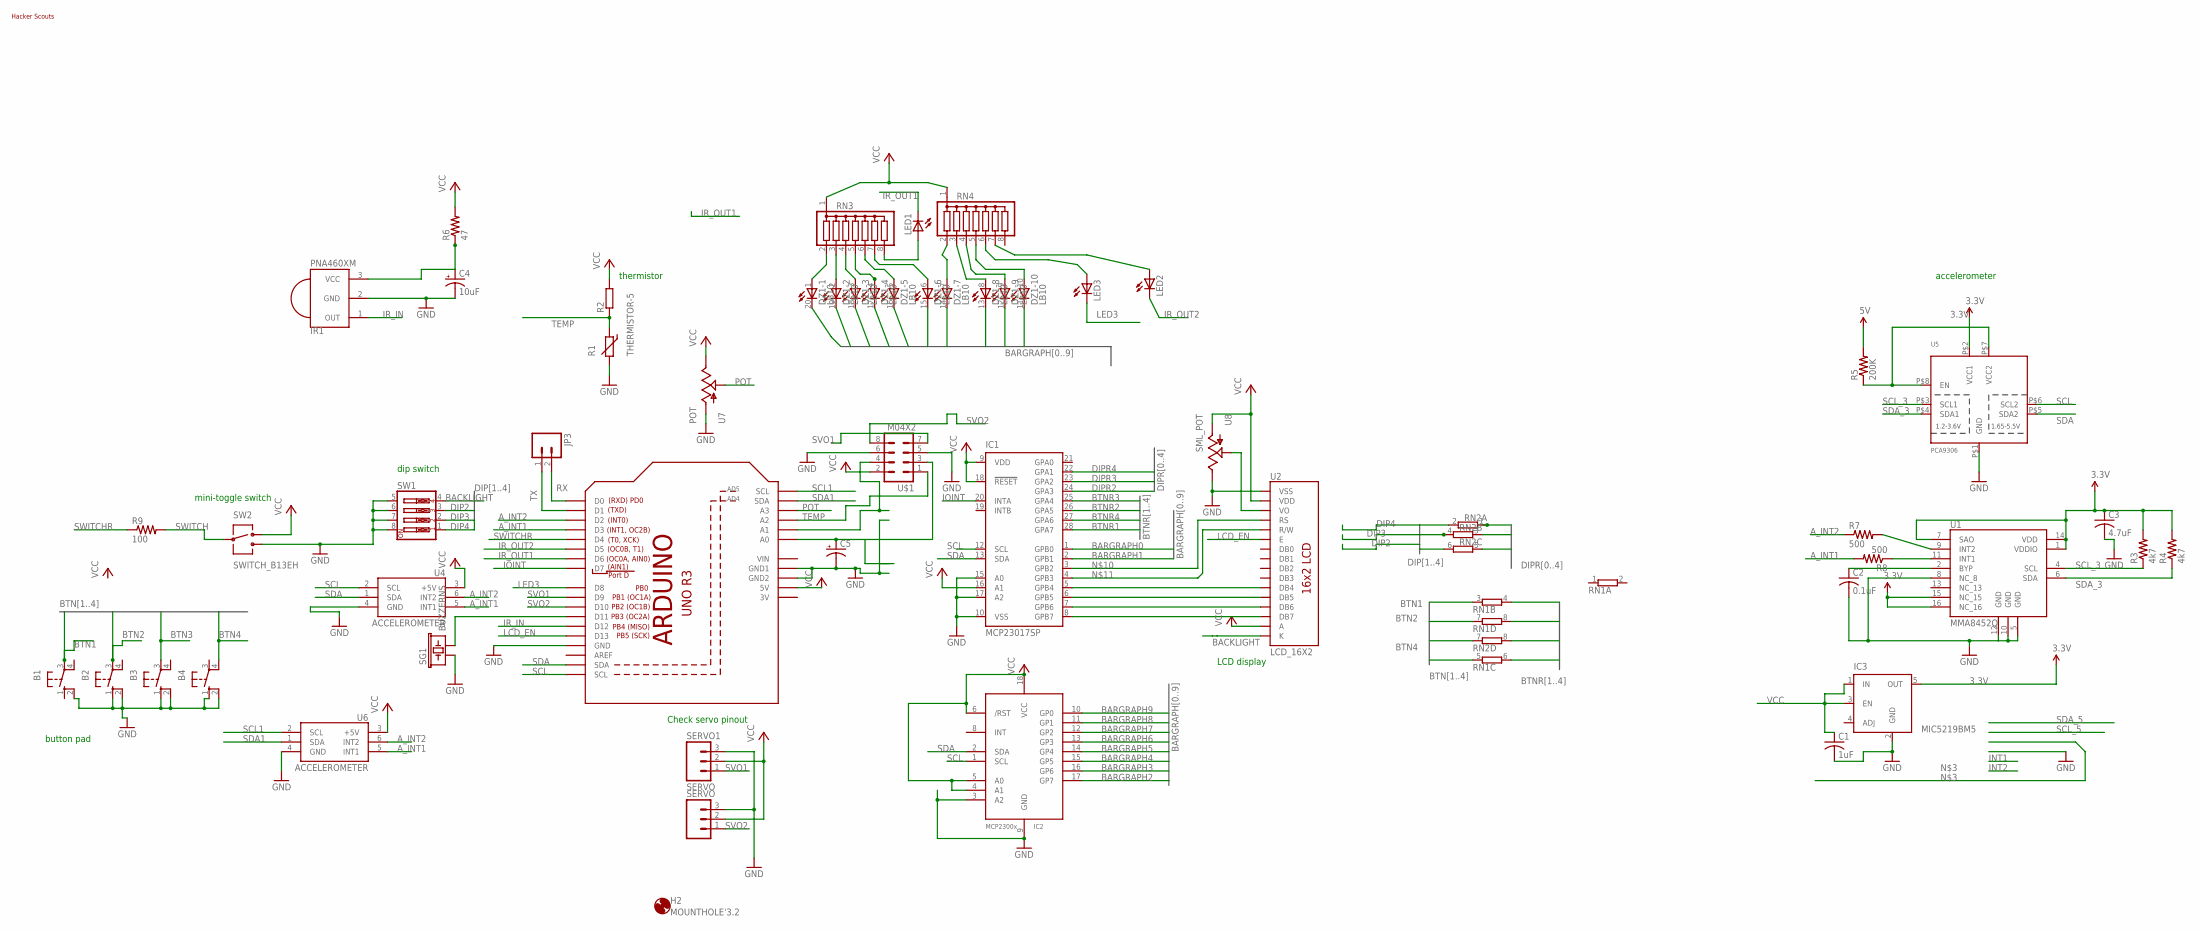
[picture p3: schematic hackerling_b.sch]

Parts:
B1, B2, B3, B4: SWITCH_BCF-4000; SWITCH_B3F-4000
C1: 1uF; C0603K
C2: 0.1uF; C0603K
C3: 4.7uF; C0603K
C4: 10uF; CAP_050X075
C5: CPOL-USE5-4; E5-4
DZ1: LB10
H2: MOUNTHOLE'3.2; HOLE_3.2
HACKERSCOUTSLOGO: HS-LOGO; HS-LOGO-SM-NOTEXT
IC1: MCP23017SP; DIL28-3
IC2: MCP2300X/P; DIL18
IC3: MIC5219BM5; SOT23-5
IR1: PNA460XM
JP3: M02LOCK; 1X02_LOCK
LED1, LED2, LED3: LED5MM
R1: THERMISTOR-5; R-5
R2: R-EU_0204/7; 0204/7
R3, R4: 4k7; 0603-RES
R5: 200K; 0603-RES
R6: 47; 0204/7
R7, R8: 500; 0603-RES
R9: 100; 0204/7
RN1, RN2: E4R; SIL8
RN3, RN4: G07R; SIL8
SERVO: M03LOCK; 1X03_LOCK
SERVO1: SERVO; 1X03_LOCK
SG1: BUZZERNS; BUZZER-12MM-NS
SW1: SW_DIP-4; EDG-04
SW2: SWITCH_B13EH
U1: MMA8452Q; QFN-16(5X3)
U2: LCD_16X2
U3: ARDUINOR3-BPLACE
U4, U6: ACCELEROMETER
U5: PCA9306; VSSOP-8
U7: POT; ALS_POT
U8: SML_POT
U$1: M04X2; 2X4

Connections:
3.3V: C3.1, IC3.5 (OUT), R3.2, R4.2, U1.1 (VDDIO), U1.7 (SAO), U1.14 (VDD), U1.15 (NC_15), U1.16 (NC_16), U5.P$2 (VCC1)
3V: U3.3V
A_INT1: R8.2, U3.D3, U4.5 (INT1), U6.5 (INT1)
A_INT2: R7.1, U3.D2, U4.6 (INT2), U6.6 (INT2)
BACKLIGHT: SW1.4, U2.16 (K)
BARGRAPH0: DZ1.20 (C), IC1.1 (GPB0)
BARGRAPH1: DZ1.19 (C), IC1.2 (GPB1)
BARGRAPH2: DZ1.18 (C), IC2.17 (GP7)
BARGRAPH3: DZ1.17 (C), IC2.16 (GP6)
BARGRAPH4: DZ1.16 (C), IC2.15 (GP5)
BARGRAPH5: DZ1.15 (C), IC2.14 (GP4)
BARGRAPH6: DZ1.14 (C), IC2.13 (GP3)
BARGRAPH7: DZ1.13 (C), IC2.12 (GP2)
BARGRAPH8: DZ1.12 (C), IC2.11 (GP1)
BARGRAPH9: DZ1.11 (C), IC2.10 (GP0)
BTN1: B1.3, RN1.3 (1)
BTN2: B2.3, RN1.7 (1)
BTN3: B3.3, RN2.7 (1)
BTN4: B4.4 (P1), RN1.5 (1)
BTNR1: IC1.28 (GPA7), RN1.4 (2)
BTNR2: IC1.26 (GPA5), RN1.8 (2)
BTNR3: IC1.25 (GPA4), RN2.8 (2)
BTNR4: IC1.27 (GPA6), RN1.6 (2)
DIP2: RN2.6 (2), SW1.3
DIP3: RN2.4 (2), SW1.2
DIP4: RN2.2, SW1.1
DIPR2: IC1.24 (GPA3), RN2.5 (1)
DIPR3: IC1.23 (GPA2), RN2.3 (1)
DIPR4: IC1.22 (GPA1), RN2.1
GND: B1.2 (S1), B2.1 (S), B2.2 (S1), B3.1 (S), B3.2 (S1), B4.1 (S), B4.2 (S1), C1.2, C2.2, C3.2, C4.2 (-), C5.-, IC1.10 (VSS), IC1.15 (A0), IC1.17 (A2), IC2.3 (A2), IC2.9 (GND), IC3.2 (GND), IR1.2 (GND), R1.2, SERVO.3, SERVO1.3, SG1.+ (1), SW1.5, SW1.6, SW1.7, SW1.8, SW2.3, U1.5 (GND), U1.8 (NC_8), U1.10 (GND), U1.12 (GND), U2.1 (VSS), U2.B1 (VSS), U3.GND, U3.GND1, U3.GND2, U4.4 (GND), U5.P$1 (GND), U6.4 (GND), U7.P$1 (A), U8.E, U$1.5, U$1.6
IOINT: IC1.20 (INTA), U3.D7
IR_IN: IR1.1 (OUT), U3.D12
IR_OUT1: LED1.K (C), U3.D6
IR_OUT2: LED2.K (C), U3.D5
LCD_EN: U2.6 (E), U3.D13
LED3: LED3.K (C), U3.D8
unnamed: IC1.8 (GPB7), U2.14 (DB7)
unnamed: IC1.7 (GPB6), U2.13 (DB6), U2.B13 (DB6)
unnamed: IC1.6 (GPB5), U2.12 (DB5), U2.B12 (DB5)
unnamed: IC1.5 (GPB4), U2.11 (DB4)
unnamed: R5.1, U5.P$7 (VCC2), U5.P$8 (EN)
unnamed: R7.2, U1.9 (INT2)
unnamed: R8.1, U1.11 (INT1)
unnamed: DZ1.2 (A), RN3.3
unnamed: DZ1.3 (A), RN3.4
unnamed: IC1.3 (GPB2), U2.4 (RS)
unnamed: IC1.4 (GPB3), U2.5 (R/W)
unnamed: LED2.A, RN4.7
unnamed: U2.3 (VO), U8.S
unnamed: SG1.- (2), U3.D11
unnamed: DZ1.7 (A), RN4.2
unnamed: DZ1.6 (A), RN3.7
unnamed: DZ1.1 (A), RN3.2
unnamed: C4.1 (+), IR1.3 (VCC), R6.1
unnamed: LED3.A, RN4.6
unnamed: DZ1.4 (A), RN3.5
unnamed: DZ1.5 (A), RN3.6
unnamed: U3.A1, U$1.4
unnamed: C2.1, U1.2 (BYP)
unnamed: C5.+, U3.A0, U$1.3
unnamed: DZ1.8 (A), RN4.3
unnamed: DZ1.9 (A), RN4.4
unnamed: DZ1.10 (A), RN4.5
unnamed: LED1.A, RN3.8
POT: U3.A3, U7.P$2 (S)
RX: JP3.2, U3.D0
SCL: IC1.12 (SCL), IC2.1 (SCL), U3.SCL, U4.2 (SCL), U5.P$6 (SCL2)
SCL1: U3.A5 (SCL), U6.2 (SCL)
SCL_3: R3.1, U1.4 (SCL), U5.P$3 (SCL1)
SDA: IC1.13 (SDA), IC2.2 (SDA), U3.SDA, U4.1 (SDA), U5.P$5 (SDA2)
SDA1: U3.A4 (SDA), U6.1 (SDA)
SDA_3: R4.1, U1.6 (SDA), U5.P$4 (SDA1)
SVO1: SERVO1.1, U3.D9, U$1.7
SVO2: SERVO.1, U3.D10, U$1.8
SWITCH: R9.2, SW2.2
SWITCHR: R9.1, U3.D4
TEMP: R1.1, R2.1, U3.A2, U$1.1
TX: JP3.1, U3.D1
VCC: C1.1, IC1.9 (VDD), IC1.16 (A1), IC1.18 (!RESET), IC2.4 (A1), IC2.5 (A0), IC2.6 (/RST), IC2.18 (VCC), IC3.1 (IN), IC3.3 (EN), R2.2, R5.2, R6.2, RN3.1, RN4.1, SERVO.2, SERVO1.2, SW2.1, U2.2 (VDD), U2.15 (A), U2.B2 (VDD), U3.5V, U4.3 (+5V), U6.3 (+5V), U7.P$3 (E), U8.A, U$1.2
VIN: U3.VIN

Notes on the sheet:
mini-toggle switch
thermistor
dip switch
LCD display
button pad
accelerometer
Check servo pinout

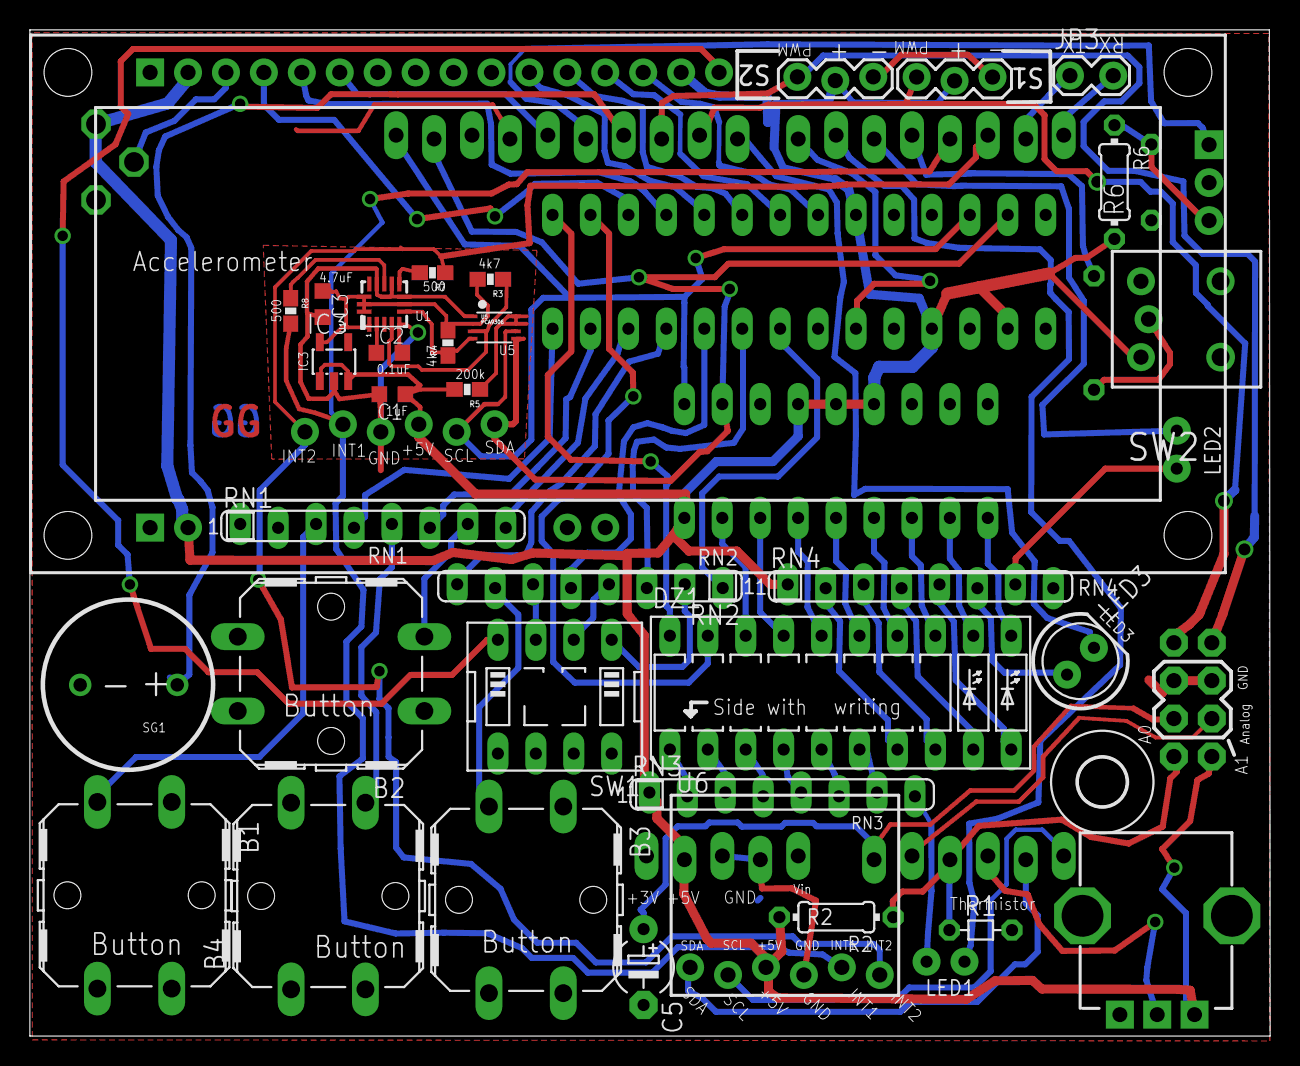
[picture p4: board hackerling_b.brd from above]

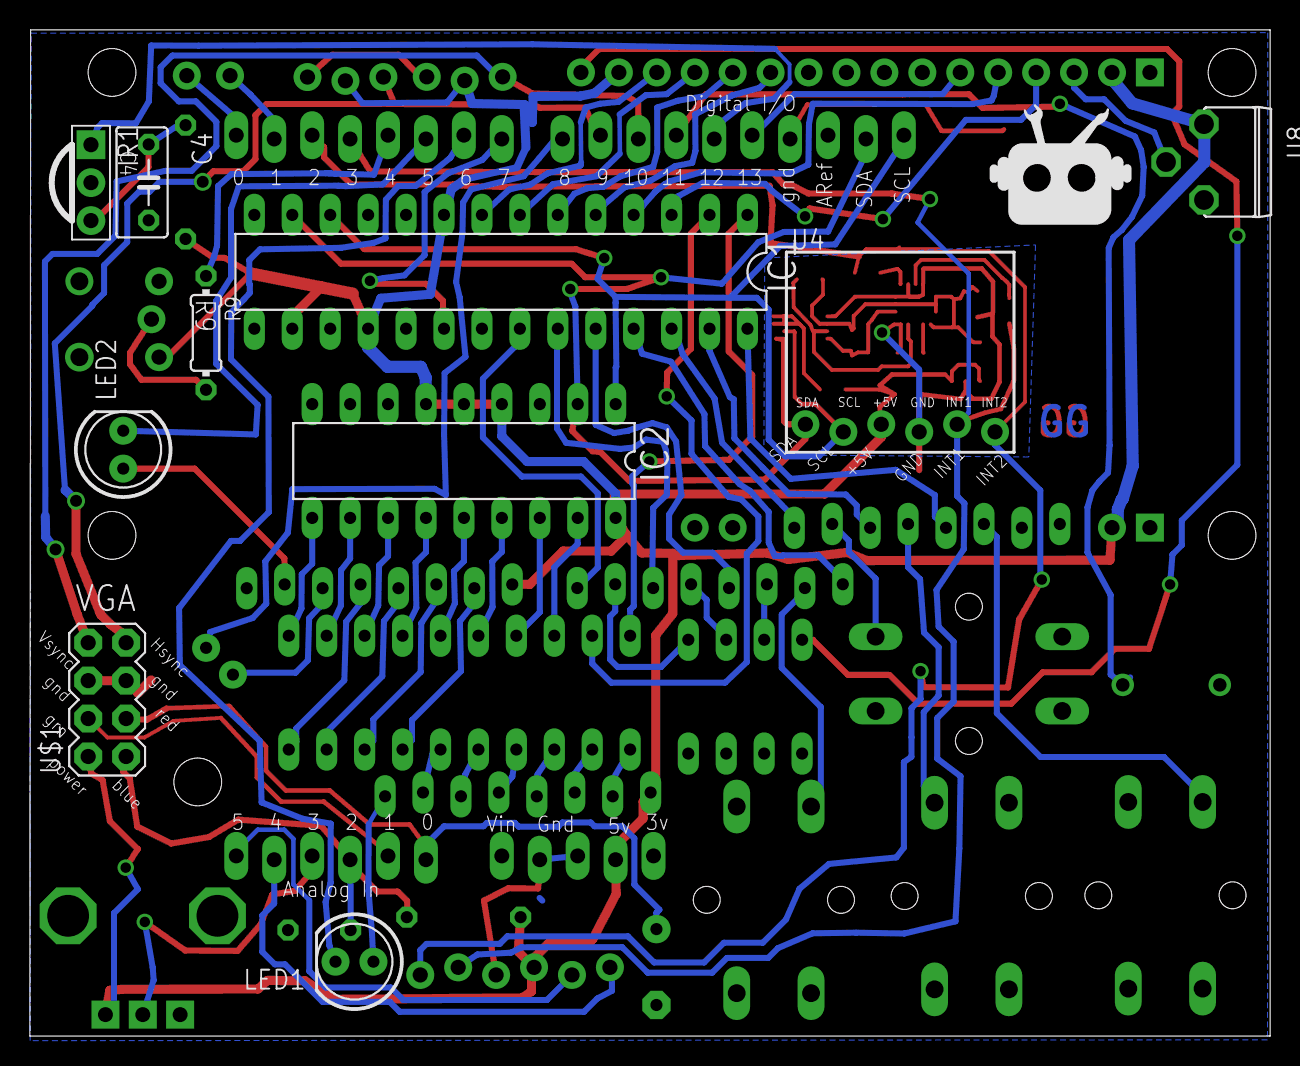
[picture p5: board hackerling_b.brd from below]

Board: 2 copper layers, 83.1 x 67.4 mm, 47 parts (11 on the bottom side), 78 nets.

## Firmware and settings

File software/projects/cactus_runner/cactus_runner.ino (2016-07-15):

#include <Wire.h>
#include <MCP23017.h>
#include <MCP23008.h>
#include <LCD.h>

MCP23017 mcp23017;
MCP23008 mcp23008;
LCD lcd = LCD();

// component to pin mapping 
const int led=8;
const int sw1p=4;
const int but3p=4;
const int but2p=5;
const int but4p=6;
const int but1p=7;

// variabes to hold switch state
int but1=0;
int but2=0;
int but3=0;
int but4=0;
int sw1=0;

//player
byte specialChar0[8] = 
  {0,14,17,21,17,14,0,0};
  
//ground 1
byte specialChar1[8] = 
  {
  B00000,
  B00000,
  B00000,
  B00000,
  B00000,
  B00000,
  B00000,
  B01000
  };
  
//ground 2
byte specialChar2[8] = 
  {
  B00000,
  B00000,
  B00000,
  B00000,
  B00000,
  B00000,
  B00000,
  B00100
  };

//ground 3
byte specialChar3[8] = 
  {
  B00000,
  B00000,
  B00000,
  B00000,
  B00000,
  B00000,
  B00000,
  B10010
  };
  
//evil cactus 1
byte specialChar4[8] =
  {
  B00100,
  B10101,
  B10101,
  B11111,
  B00100,
  B00100,
  B00100,
  B00000
  };

//evil cactus 2  
byte specialChar5[8] = 
  {
  B00100,
  B10100,
  B10101,
  B11101,
  B00111,
  B00100,
  B00100,
  B00000
  };

//evil cactus 3
byte specialChar6[8] = 
  {
  B00100,
  B10100,
  B10100,
  B11111,
  B00101,
  B00100,
  B00100,
  B00000
  };

//evil cactus 4
byte specialChar7[8] = 
  {
  B00100,
  B00100,
  B11111,
  B10101,
  B10100,
  B00100,
  B00100
  };

  // player and shot icons
  //const int player = B11101111;
  const int player = 0;
  const int shot = B11101011;

  //initial values
  int counter;
  int ppos;
  int bpos;
  int jump;
  int shots;
  int field[16];

void readSwitches() {
        but1 = mcp23017.digitalRead(but1p);
        but2 = mcp23017.digitalRead(but2p);
        but3 = mcp23017.digitalRead(but3p); 
        but4 = mcp23017.digitalRead(but4p); 
        sw1 = digitalRead(sw1p);
}

void initLCD() {

    lcd.clear();
    lcd.setCursor(0,0);
}

void beep() {
  tone(11, 440, 70);
}

void boop() {
  tone(11,300,100);
}

void clearBargraph(){
          for(int i=0;i<8;i++){
                mcp23008.digitalWrite(i, 1);// set pin to high (turns LED off)
        }
        for(int i=8;i<10;i++){
                mcp23017.digitalWrite(i, 1);// set pin to high (turns LED off)
        }
}

void setBargraph(int a){
  // set lights on bargraph
  if ( a < 8 ) {
      mcp23008.digitalWrite(a, 0);
  }
  if ( a == 8 ){ mcp23017.digitalWrite(9, 0); }
  if ( a == 9 ){ mcp23017.digitalWrite(8, 0); } 

}

void graphTo(int a){
  // set all lights up to
  clearBargraph();
  for(int i=0;i<=a;i++){
    setBargraph(i);
  }
}

void displayCount(){
    int cnt = counter;
    int dgts = 1; 
    while(cnt!=0)
    {
        cnt /= 10;             // n = n/10
        ++dgts;
    }
    lcd.setCursor(17-dgts,0);
    lcd.print(counter);
}

void displayRun() {
  // show the field
  for (int i=0;i<16;i++) {
    if ( i != ppos || jump == 0) {
      lcd.setCursor(i,1);
      lcd.write(field[i]);   
    }
  }
  if (bpos > 0 ){
    lcd.setCursor(bpos,1);
    lcd.write(shot); 
  }
  lcd.setCursor(ppos,jump);
  lcd.write(player);
}

void moveRight() {
  if (ppos < 14) { ++ppos; }
}

void moveLeft() {
  if (ppos > 0) { --ppos; }
}

void shoot() {
  // fire!
  if (shots > 0){
    --shots;
    graphTo(shots-1);
    bpos = ppos + 1;
  }
}
void updateField() {
  for (int i=0; i<15 ; i++){
    field[i] = field[i+1];
  }
  // a blank, ground 1, ground 2, ground 3, a cactus1-4, another blank
  int r = int(random(0,6));
  if ( r == 0 || r == 5) { field[15] = 32; }
  if ( r == 1 ) { field[15] = 1; }
  if ( r == 2 ) { field[15] = 2; }
  if ( r == 3 ) { field[15] = 3; }
  if ( r == 4 ) {
      field[15] = int(random(4,8));
  }
}

void moveShot(){
  if (bpos > 0 && bpos < 14) {
    ++bpos;
    }
    else { bpos = 0; }
}

byte detectCollision(int pos, int jmp) {
    // did we hit something
    if (field[pos] >= 4 && field[pos] < 8 && jmp != 0) {
      return true;
    } else { return false; }
}

void setup() {
  // put your setup code here, to run once:

  // initialize toggle
  pinMode(sw1p, INPUT);

  // initialize IO expander 
  mcp23017.begin(2);  
  mcp23008.begin(3);  

  // tell the switch pins we will be reading from them and set pullUp resistor
  mcp23017.pinMode(but1p, INPUT);
  mcp23017.pinMode(but2p, INPUT);
  mcp23017.pinMode(but3p, INPUT);
  mcp23017.pinMode(but4p, INPUT);
  mcp23017.pullUp(but1p, 1);
  mcp23017.pullUp(but2p, 1);
  mcp23017.pullUp(but3p, 1);
  mcp23017.pullUp(but4p, 1);

// tell bargraph pins we will write to them and set inital state as off
  for(int i=0;i<8;i++){
          mcp23008.pinMode(i, 1);// set pin to output
  }
  for(int i=8;i<10;i++){
          mcp23017.pinMode(i, 1);// set pin to output
  }
  clearBargraph();
  
  // initialize LED
  pinMode(led,OUTPUT);
  digitalWrite(led,HIGH);

  // initialize LCD
  lcd.begin(16,2);

  lcd.createChar(0,specialChar0);
  lcd.createChar(1,specialChar1);
  lcd.createChar(2,specialChar2);
  lcd.createChar(3,specialChar3);
  lcd.createChar(4,specialChar4);
  lcd.createChar(5,specialChar5);
  lcd.createChar(6,specialChar6);
  lcd.createChar(7,specialChar7);

  initLCD();

  randomSeed(analogRead(0));

  resetGame();

}

void resetGame() {
    counter = 0;
    ppos = 0;
    bpos = 0;
    shots = 5;
    jump = 1;
    for (int i=0; i<16; i++) { 
        int r = int(random(0,5));
        if ( r == 0 || r == 4) { field[i] = 32; }
        if ( r == 1 ) { field[i] = 1; }
        if ( r == 2 ) { field[i] = 2; }
        if ( r == 3 ) { field[i] = 3; }
    }
    lcd.clear();  
    graphTo(shots-1);
}

void loop() {
  // put your main code here, to run repeatedly:  
  readSwitches();
  if ( but2 == 0) {
    if ( jump != 0 ) {
      beep();
    }
    jump = 0;
    }
    else if (jump == 0 ) {
        lcd.setCursor(ppos,jump);
        lcd.write(32);
        jump = 1;
        boop();
    }
  if ( but3 == 0 ) { moveRight(); }
  if ( but1 == 0 ) { moveLeft(); }
  if ( but4 == 0 ) { shoot(); }
  // lcd.setCursor(4,0); lcd.print(but1); lcd.print(but2); lcd.print(but3); lcd.print(but4); lcd.print(sw1); lcd.print(jump); //debug
  // did we shoot something?
  if (bpos > 0 ) {
    if (detectCollision(bpos, 1)) {
        field[bpos] = 32; 
        bpos = 0;
    }
    if (detectCollision(bpos-1, 1)) {
      field[bpos-1] = 32;
      bpos = 0;
    }
  }
  
  // did we run into something?
  if (detectCollision(ppos, jump)) { 
    lcd.setCursor(5,1);
    lcd.print("BOOM!");
    while (but4 == 1) { readSwitches(); } // down button to restart
    resetGame();
  }
  
  displayCount();
  displayRun();

  delay(200);

  updateField();
  moveShot();  
  ++counter;

}

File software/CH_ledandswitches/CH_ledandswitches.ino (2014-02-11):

/*
Tests big switch and 3dip switches of a v1.3 Hackerling Circuit but also testing lights from the LED array.

Uses direct library calls, to MCP libraries rather then Hackerling Circuit library code.

*/


#include <Wire.h>
#include <MCP23017.h>
#include <MCP23008.h>

MCP23008 mcp23008;
MCP23017 mcp23017; 

// define pin locations for switches and lights
int led=8;
int sw1p=4;
int dip2p=3;
int dip3p=2;
int dip4p=1;

// variabes to hold switch state
int sw1=0;
int dip2=0;
int dip3=0;
int dip4=0;


void setup() {
  
// init the IO expanders
mcp23017.begin(2);
mcp23008.begin(3);  

// tell the switch pins we will be reading from them and set pullUp resistor
pinMode(sw1p, INPUT);
mcp23017.pinMode(dip2p, INPUT);
mcp23017.pinMode(dip3p, INPUT);
mcp23017.pinMode(dip4p, INPUT);
mcp23017.pullUp(dip2p, 1);
mcp23017.pullUp(dip3p, 1);
mcp23017.pullUp(dip4p, 1);

// tell LED pins we will write to them and set inital state as off
        pinMode(led, OUTPUT);

        for(int i=0;i<8;i++){
                mcp23008.pinMode(i, 1);// set pin to output
                mcp23008.digitalWrite(i, 1);// set pin to high (turns LED off)
        }
        for(int i=8;i<10;i++){
                mcp23017.pinMode(i, 1);// set pin to output
                mcp23017.digitalWrite(i, 1);// set pin to high (turns LED off)
        }
        digitalWrite(led, HIGH);   // turn the LED off
        
 // blink to show program loaded and ready to roll       
        for(int i=0;i<4;i++){
          allSet(LOW);
          delay(400);
          allSet(HIGH);
          delay(400);
        }
}

void readSwitches() {
        sw1 = digitalRead(sw1p);
        dip2 = mcp23017.digitalRead(dip2p);
        dip3 = mcp23017.digitalRead(dip3p);
        dip4 = mcp23017.digitalRead(dip4p); 
}

void allSet(int a) {
    for(int i=0;i<8;i++){
              mcp23008.digitalWrite(i, a);
    }
    for(int i=9;i>=8;i--){
              mcp23017.digitalWrite(i, a);
    }     
    digitalWrite(led, a);     
}
 
void loop() {

  readSwitches();
       
      digitalWrite(led, sw1);

      // turn on two bar lights per switch
      mcp23017.digitalWrite(9, dip2);
      mcp23008.digitalWrite(7, dip2);

      mcp23008.digitalWrite(5, dip3);
      mcp23008.digitalWrite(4, dip3);      

      mcp23008.digitalWrite(2, dip4);
      mcp23008.digitalWrite(1, dip4);
 
  delay(1000); //dont run too often

}

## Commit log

2014-02-11 additional test examples for switches and LEDs
2014-02-18 add in button / speaker test
2014-07-18 Adding chat system project.
    It's a basic chat system library with two hackerling circuits (can be easly extended to more than 2).
    An example of main is given in the software/projects/chat_system/ directory.
2014-10-16 Latest tested enclosure designs
    [HackerlingBoxAcrylicFixed.dxf]
